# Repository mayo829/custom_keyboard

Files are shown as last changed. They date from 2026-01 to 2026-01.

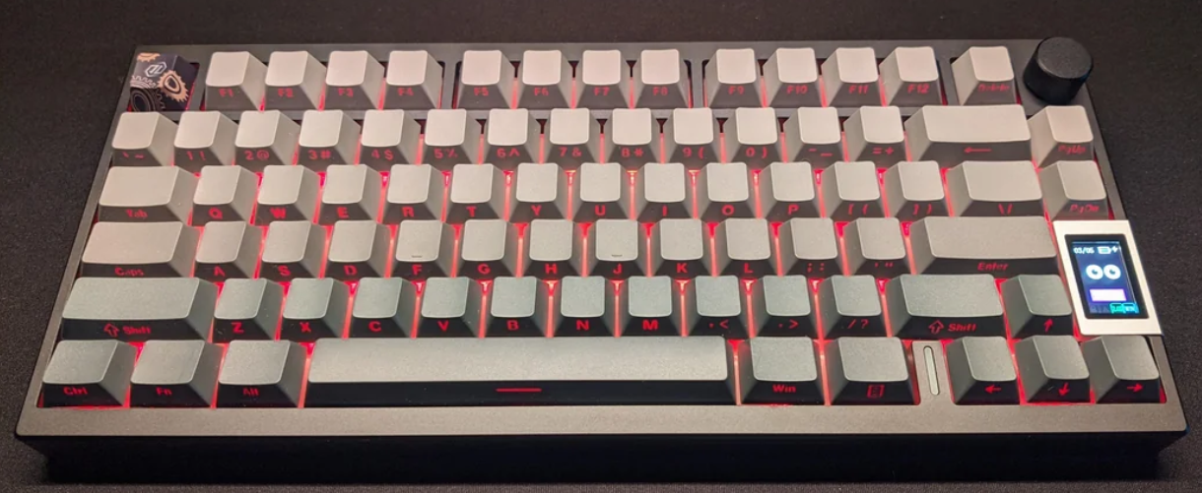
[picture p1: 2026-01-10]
Screenshot 2026-01-09 184816.png

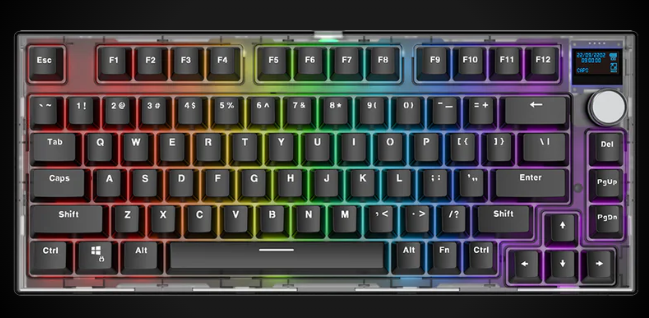
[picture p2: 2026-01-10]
Screenshot 2026-01-09 185157.png

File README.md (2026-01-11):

# Customized keyboard from scratch!

## Requirements
| Device | Requirement Met | Part number |
| LCD display | 0 |
| knob | 0 |
| [rgb backlit](https://www.digikey.com/en/products/detail/sparkfun-electronics/COM-24837/22321085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) | 0 | COM-24837 |
| addressable rgb key lighting | 0 |
| somehow layout the normal 60% plus pgup, pgdn, del, arrows, lcd, and knob and find compatible keycaps (60% keyboard with one extra column) | 0 |
| keycaps need to be, shine-through, square, | 0 |
| case and other stuff to house the keyboard nicely | 0 |
| usbc | 0 |

## BOM
- Mcus:
   - [STM32](https://www.digikey.com/en/products/detail/stmicroelectronics/STM32F072RBT6/4815291s)

- OLED display:
   - [display]()

- Encoder:
   - [encoder](https://www.digikey.com/en/products/detail/bourns-inc/PEC11R-4315K-S0024/7314924)
   - [knob](https://www.digikey.com/en/products/detail/adafruit-industries-llc/5527/16653407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)

- Keycaps
  - [165 key white, grey, red](https://www.aliexpress.us/item/3256803996803052.html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)
  - [correct cool colors](https://www.aliexpress.us/item/3256809279540220.html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)
  
- Switches
  - [Cherry MX2A Silent Red](https://mechanicalkeyboards.com/products/cherry-mx2a-silent-red-45g-linear?variant=48014625145132)

## Resources
- [good guide](https://github.com/ruiqimao/keyboard-pcb-guide)
- [community for keyboard designs](https://kbatelier.org/)
- [reference tutorial](https://www.youtube.com/watch?v=u13yRbBiRYM)

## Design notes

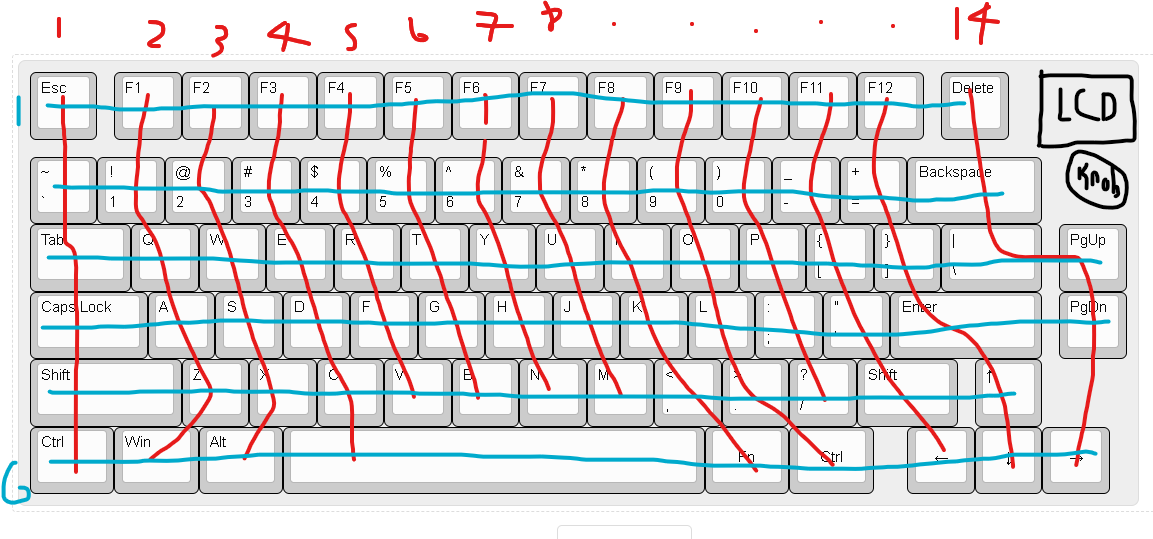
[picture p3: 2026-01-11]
keyboard_layout_image.png

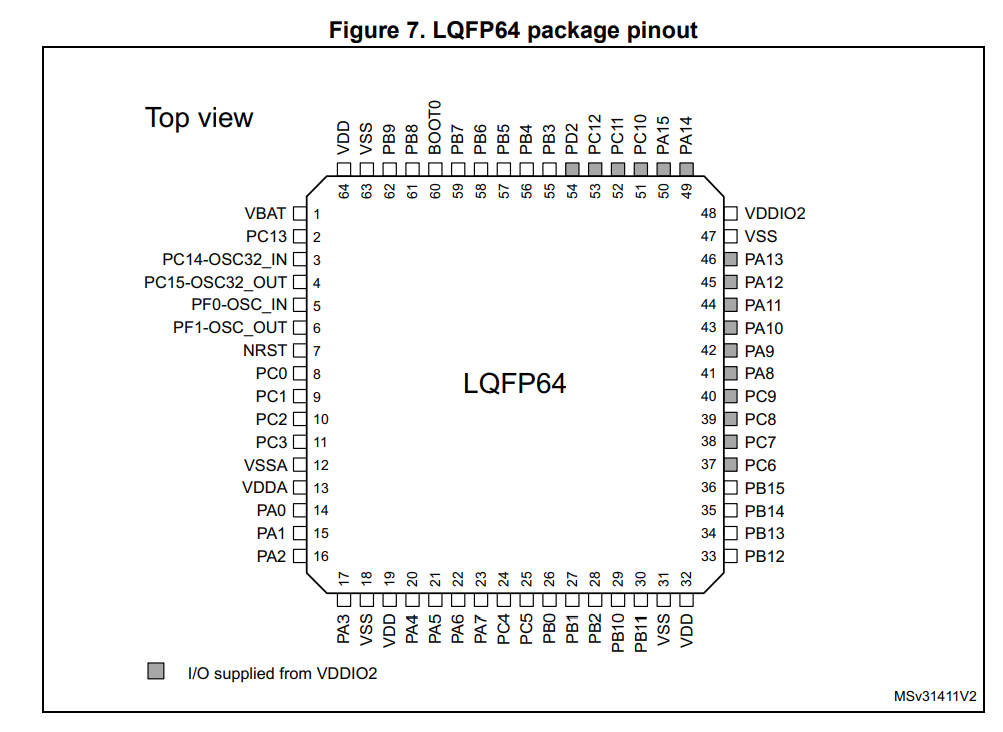
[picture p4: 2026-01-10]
stm32f072rbt6.png

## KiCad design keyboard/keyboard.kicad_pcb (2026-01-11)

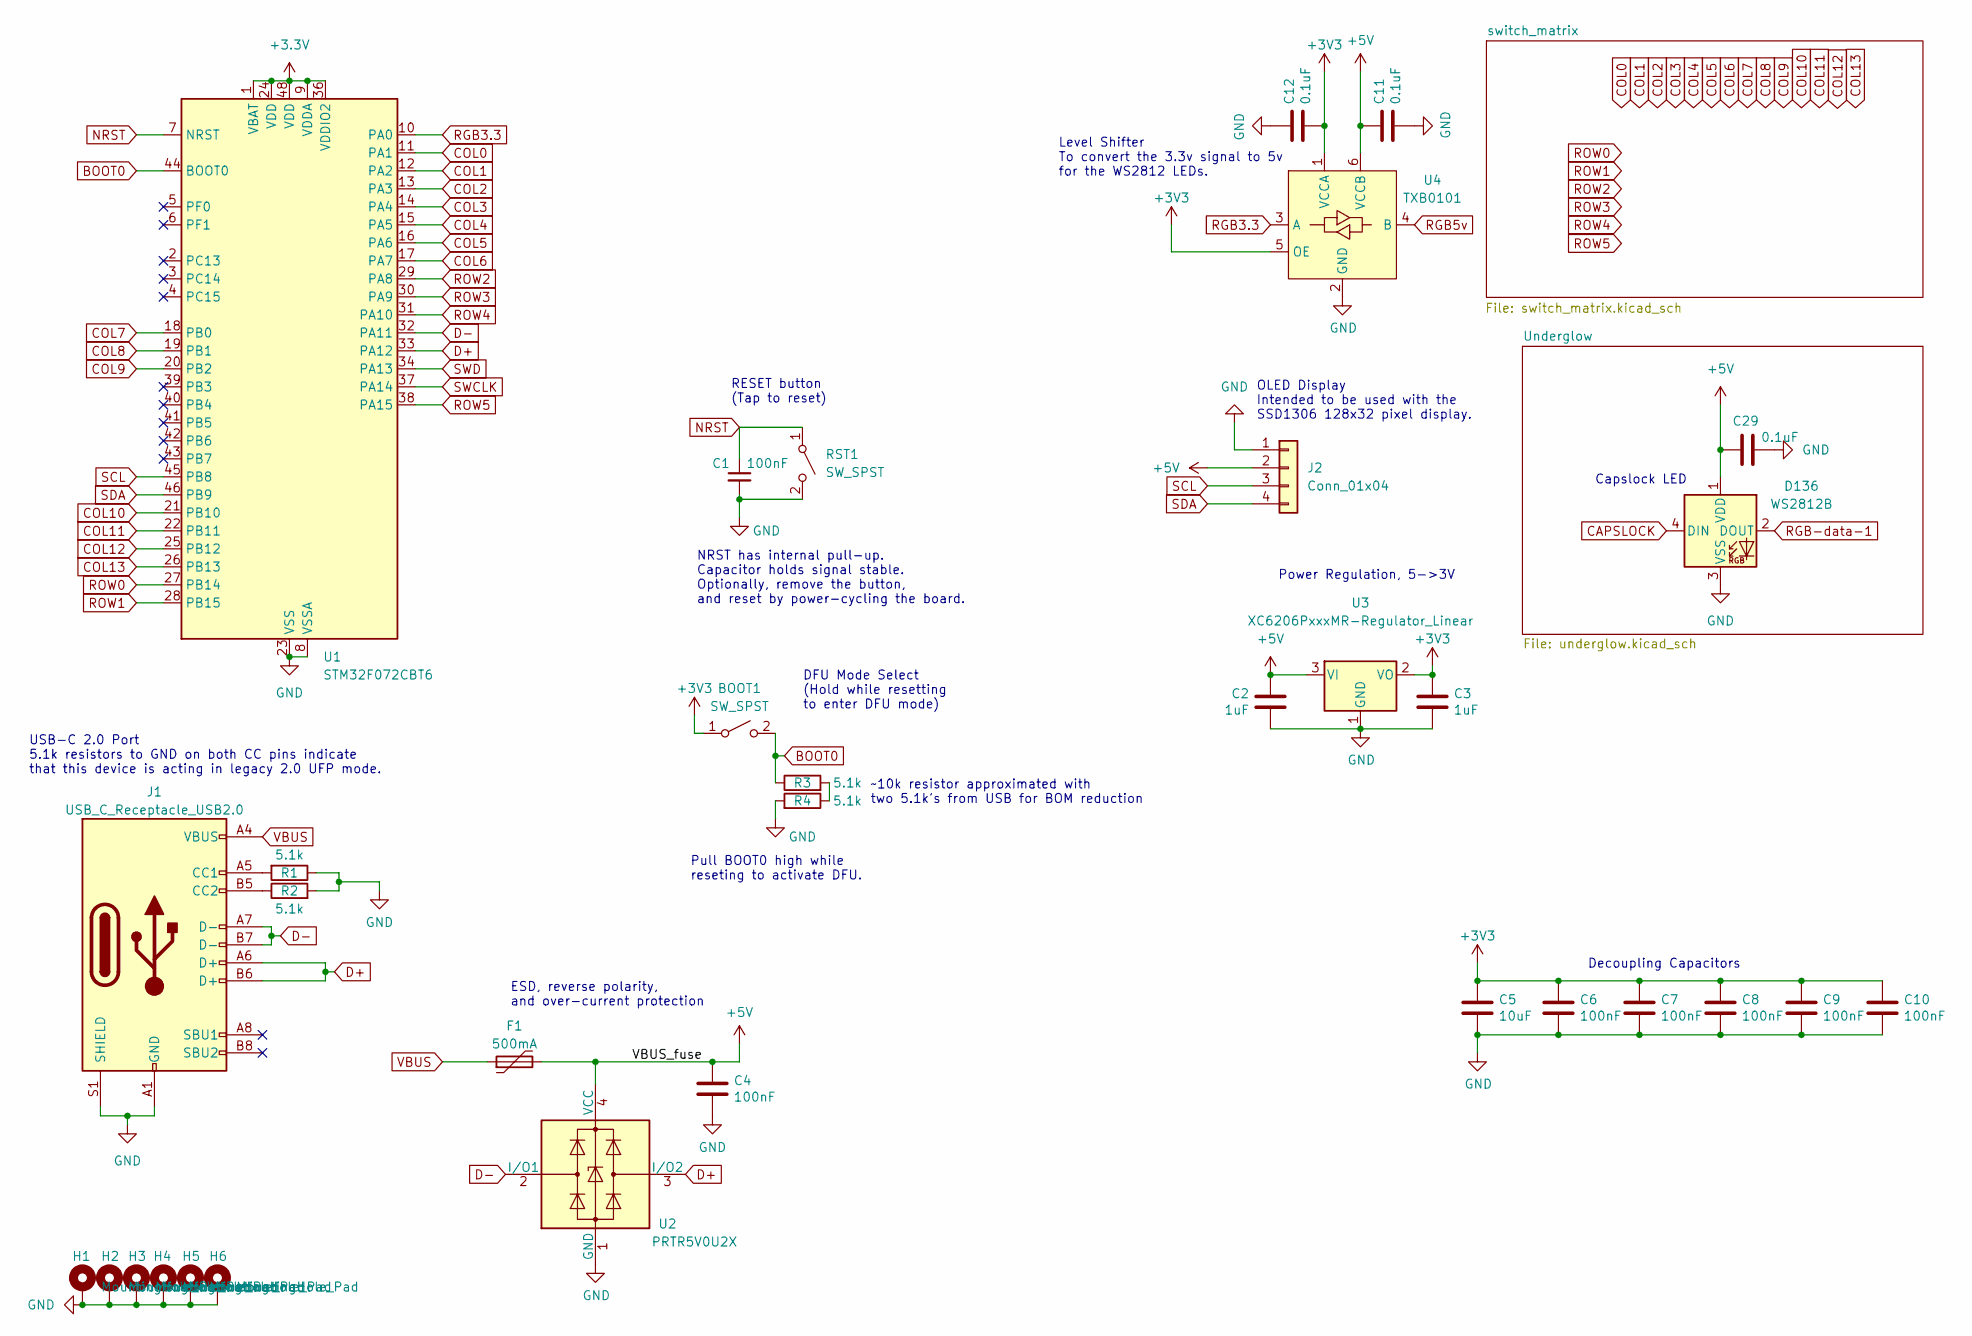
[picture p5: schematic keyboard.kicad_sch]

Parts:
BOOT1: SW_SPST; SW_SPST_TL3342
C1, C4, C6, C7, C8, C9, C10: 100nF; C_0402_1005Metric; LCSC C307331
C2, C3: 1uF; C_0402_1005Metric; LCSC C307331
C5: 10uF; C_0603_1608Metric; LCSC C307331
C11, C12: 0.1uF; C_0402_1005Metric; LCSC C307331
C29: 0.1uF; C_0402_1005Metric
D136: WS2812B; LED_WS2812B_PLCC4_5.0x5.0mm_P3.2mm
F1: 500mA; Fuse_1206_3216Metric; LCSC C135341
H1, H2, H3, H4, H5, H6: MountingHole_Pad; MountingHole_3.2mm_M3
J1: USB_C_Receptacle_USB2.0; USB_C_Receptacle_HRO_TYPE-C-31-M-14; JlcRotOffset 180
J2: Conn_01x04; SSD1306-0.91-OLED-4pin-128x32
R1, R2, R3, R4: 5.1k; R_0402_1005Metric
RST1: SW_SPST; SW_SPST_TL3342
U1: STM32F072CBT6; LQFP-48_7x7mm_P0.5mm
U2: PRTR5V0U2X; SOT-143; LCSC C2827688
U3: XC6206PxxxMR-Regulator_Linear; SOT-23; LCSC C5446
U4: TXB0101; SOT-363_SC-70-6_Handsoldering; LCSC C324081

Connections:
+3.3V: U1.1 (VBAT), U1.9 (VDDA), U1.24 (VDD), U1.36 (VDDIO2), U1.48 (VDD)
+3V3: BOOT1.1 (A), C3.1, C5.1, C6.1, C7.1, C8.1, C9.1, C10.1, C12.2, U3.2 (VO), U4.1 (VCCA), U4.5 (OE)
+5V: C2.1, C4.1, C11.1, C29.1, D136.1 (VDD), F1.2, J2.2, U2.4 (VCC), U3.3 (VI), U4.6 (VCCB); also elsewhere on the board
BOOT0: BOOT1.2 (B), R3.1, U1.44 (BOOT0)
CAPSLOCK: D136.4 (DIN); also elsewhere on the board
COL0: U1.11 (PA1); also elsewhere on the board
COL1: U1.12 (PA2); also elsewhere on the board
COL2: U1.13 (PA3); also elsewhere on the board
COL3: U1.14 (PA4); also elsewhere on the board
COL4: U1.15 (PA5); also elsewhere on the board
COL5: U1.16 (PA6); also elsewhere on the board
COL6: U1.17 (PA7); also elsewhere on the board
COL7: U1.18 (PB0); also elsewhere on the board
COL8: U1.19 (PB1); also elsewhere on the board
COL9: U1.20 (PB2); also elsewhere on the board
COL10: U1.21 (PB10); also elsewhere on the board
COL11: U1.22 (PB11); also elsewhere on the board
COL12: U1.25 (PB12); also elsewhere on the board
COL13: U1.26 (PB13); also elsewhere on the board
D+: J1.A6 (D+), J1.B6 (D+), U1.33 (PA12), U2.3 (I/O2)
D-: J1.A7 (D-), J1.B7 (D-), U1.32 (PA11), U2.2 (I/O1)
GND: C1.2, C2.2, C3.2, C4.2, C5.2, C6.2, C7.2, C8.2, C9.2, C10.2, C11.2, C12.1, C29.2, D136.3 (VSS), H1.1, H2.1, H3.1, H4.1, H5.1, H6.1, J1.A1 (GND), J1.A12 (GND), J1.B1 (GND), J1.B12 (GND), J1.S1 (SHIELD), J2.1, R1.1, R2.2, R4.2, RST1.2 (B), U1.8 (VSSA), U1.23 (VSS), U1.35 (VSS), U1.47 (VSS), U2.1 (GND), U3.1 (GND), U4.2 (GND); also elsewhere on the board
NRST: C1.1, RST1.1 (A), U1.7 (NRST)
unnamed: J1.A5 (CC1), R1.2
unnamed: J1.B5 (CC2), R2.1
unnamed: R3.2, R4.1
RGB3.3: U1.10 (PA0), U4.3 (A)
RGB5v: U4.4 (B); also elsewhere on the board
RGB-data-1: D136.2 (DOUT); also elsewhere on the board
ROW0: U1.27 (PB14); also elsewhere on the board
ROW1: U1.28 (PB15); also elsewhere on the board
ROW2: U1.29 (PA8); also elsewhere on the board
ROW3: U1.30 (PA9); also elsewhere on the board
ROW4: U1.31 (PA10); also elsewhere on the board
ROW5: U1.38 (PA15); also elsewhere on the board
SCL: J2.3, U1.45 (PB8)
SDA: J2.4, U1.46 (PB9)
SWCLK: U1.37 (PA14)
SWD: U1.34 (PA13)
VBUS: F1.1, J1.A4 (VBUS), J1.A9 (VBUS), J1.B4 (VBUS), J1.B9 (VBUS)

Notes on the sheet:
Decoupling Capacitors
~10k resistor approximated with two 5.1k's from USB for BOM reduction
RESET button (Tap to reset)
Power Regulation, 5->3V
Pull BOOT0 high while reseting to activate DFU.
Capslock LED
USB-C 2.0 Port 5.1k resistors to GND on both CC pins indicate that this device is acting in legacy 2.0 UFP mode.
NRST has internal pull-up. Capacitor holds signal stable. Optionally, remove the button, and reset by power-cycling the board.
ESD, reverse polarity, and over-current protection
Level Shifter To convert the 3.3v signal to 5v for the WS2812 LEDs.
OLED Display Intended to be used with the SSD1306 128x32 pixel display.
DFU Mode Select (Hold while resetting to enter DFU mode)

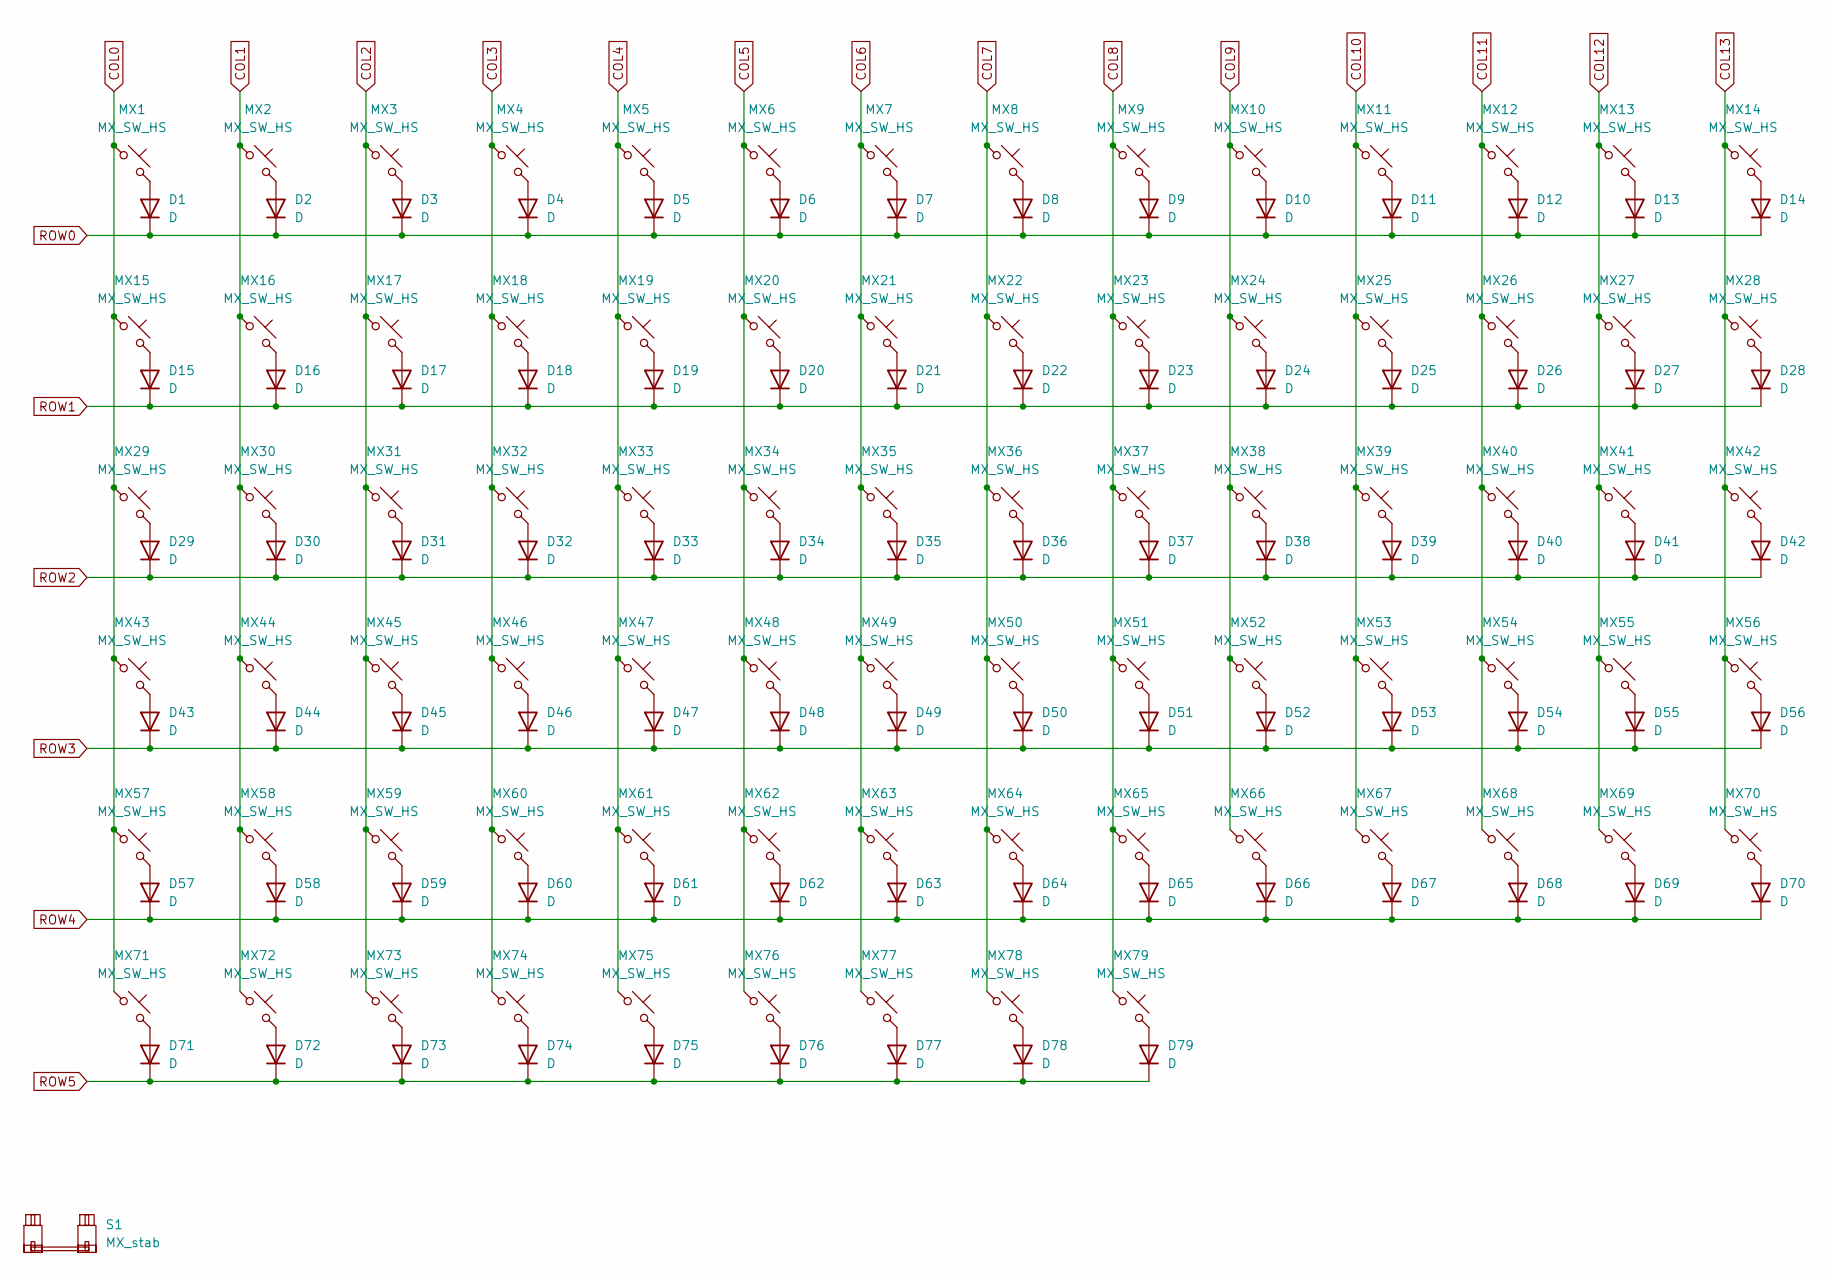
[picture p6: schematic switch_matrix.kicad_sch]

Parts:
D1, D2, D3, D4, D5, D6, D7, D8, D9, D10, D11, D12, D13, D14, D15, D16, D17, D18, D19, D20, D21, D22, D23, D24, D25, D26, D27, D28, D29, D30, D31, D32, D33, D34, D35, D36, D37, D38, D39, D40, D41, D42, D43, D44, D45, D46, D47, D48, D49, D50, D51, D52, D53, D54, D55, D56, D57, D58, D59, D60, D61, D62, D63, D64, D65, D66, D67, D68, D69, D70, D71, D72, D73, D74, D75, D76, D77, D78, D79: D; D_SOD-123
MX1, MX2, MX3, MX4, MX5, MX6, MX7, MX8, MX9, MX10, MX11, MX12, MX13, MX14, MX15, MX16, MX17, MX18, MX19, MX20, MX21, MX22, MX23, MX24, MX25, MX26, MX27, MX28, MX29, MX30, MX31, MX32, MX33, MX34, MX35, MX36, MX37, MX38, MX39, MX40, MX41, MX42, MX43, MX44, MX45, MX46, MX47, MX48, MX49, MX50, MX51, MX52, MX53, MX54, MX55, MX56, MX57, MX58, MX59, MX60, MX61, MX62, MX63, MX64, MX65, MX66, MX67, MX68, MX69, MX70, MX71, MX72, MX73, MX74, MX75, MX76, MX77, MX78, MX79: MX_SW_HS; SW_MX_HS_CPG151101S11_1u
S1: MX_stab; STAB_MX_P_6.25u

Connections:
COL0: MX1.1, MX15.1, MX29.1, MX43.1, MX57.1, MX71.1; also elsewhere on the board
COL1: MX2.1, MX16.1, MX30.1, MX44.1, MX58.1, MX72.1; also elsewhere on the board
COL2: MX3.1, MX17.1, MX31.1, MX45.1, MX59.1, MX73.1; also elsewhere on the board
COL3: MX4.1, MX18.1, MX32.1, MX46.1, MX60.1, MX74.1; also elsewhere on the board
COL4: MX5.1, MX19.1, MX33.1, MX47.1, MX61.1, MX75.1; also elsewhere on the board
COL5: MX6.1, MX20.1, MX34.1, MX48.1, MX62.1, MX76.1; also elsewhere on the board
COL6: MX7.1, MX21.1, MX35.1, MX49.1, MX63.1, MX77.1; also elsewhere on the board
COL7: MX8.1, MX22.1, MX36.1, MX50.1, MX64.1, MX78.1; also elsewhere on the board
COL8: MX9.1, MX23.1, MX37.1, MX51.1, MX65.1, MX79.1; also elsewhere on the board
COL9: MX10.1, MX24.1, MX38.1, MX52.1, MX66.1; also elsewhere on the board
COL10: MX11.1, MX25.1, MX39.1, MX53.1, MX67.1; also elsewhere on the board
COL11: MX12.1, MX26.1, MX40.1, MX54.1, MX68.1; also elsewhere on the board
COL12: MX13.1, MX27.1, MX41.1, MX55.1, MX69.1; also elsewhere on the board
COL13: MX14.1, MX28.1, MX42.1, MX56.1, MX70.1; also elsewhere on the board
unnamed: D1.2 (A), MX1.2
unnamed: D2.2 (A), MX2.2
unnamed: D3.2 (A), MX3.2
unnamed: D4.2 (A), MX4.2
unnamed: D5.2 (A), MX5.2
unnamed: D6.2 (A), MX6.2
unnamed: D7.2 (A), MX7.2
unnamed: D8.2 (A), MX8.2
unnamed: D9.2 (A), MX9.2
unnamed: D10.2 (A), MX10.2
unnamed: D11.2 (A), MX11.2
unnamed: D12.2 (A), MX12.2
unnamed: D13.2 (A), MX13.2
unnamed: D14.2 (A), MX14.2
unnamed: D15.2 (A), MX15.2
unnamed: D16.2 (A), MX16.2
unnamed: D17.2 (A), MX17.2
unnamed: D18.2 (A), MX18.2
unnamed: D19.2 (A), MX19.2
unnamed: D20.2 (A), MX20.2
unnamed: D21.2 (A), MX21.2
unnamed: D22.2 (A), MX22.2
unnamed: D23.2 (A), MX23.2
unnamed: D24.2 (A), MX24.2
unnamed: D25.2 (A), MX25.2
unnamed: D26.2 (A), MX26.2
unnamed: D27.2 (A), MX27.2
unnamed: D28.2 (A), MX28.2
unnamed: D29.2 (A), MX29.2
unnamed: D30.2 (A), MX30.2
unnamed: D31.2 (A), MX31.2
unnamed: D32.2 (A), MX32.2
unnamed: D33.2 (A), MX33.2
unnamed: D34.2 (A), MX34.2
unnamed: D35.2 (A), MX35.2
unnamed: D36.2 (A), MX36.2
unnamed: D37.2 (A), MX37.2
unnamed: D38.2 (A), MX38.2
unnamed: D39.2 (A), MX39.2
unnamed: D40.2 (A), MX40.2
unnamed: D41.2 (A), MX41.2
unnamed: D42.2 (A), MX42.2
unnamed: D43.2 (A), MX43.2
unnamed: D44.2 (A), MX44.2
unnamed: D45.2 (A), MX45.2
unnamed: D46.2 (A), MX46.2
unnamed: D47.2 (A), MX47.2
unnamed: D48.2 (A), MX48.2
unnamed: D49.2 (A), MX49.2
unnamed: D50.2 (A), MX50.2
unnamed: D51.2 (A), MX51.2
unnamed: D52.2 (A), MX52.2
unnamed: D53.2 (A), MX53.2
unnamed: D54.2 (A), MX54.2
unnamed: D55.2 (A), MX55.2
unnamed: D56.2 (A), MX56.2
unnamed: D57.2 (A), MX57.2
unnamed: D58.2 (A), MX58.2
unnamed: D59.2 (A), MX59.2
unnamed: D60.2 (A), MX60.2
unnamed: D61.2 (A), MX61.2
unnamed: D62.2 (A), MX62.2
unnamed: D63.2 (A), MX63.2
unnamed: D64.2 (A), MX64.2
unnamed: D65.2 (A), MX65.2
unnamed: D66.2 (A), MX66.2
unnamed: D67.2 (A), MX67.2
unnamed: D68.2 (A), MX68.2
unnamed: D69.2 (A), MX69.2
unnamed: D70.2 (A), MX70.2
unnamed: D71.2 (A), MX71.2
unnamed: D72.2 (A), MX72.2
unnamed: D73.2 (A), MX73.2
unnamed: D74.2 (A), MX74.2
unnamed: D75.2 (A), MX75.2
unnamed: D76.2 (A), MX76.2
unnamed: D77.2 (A), MX77.2
unnamed: D78.2 (A), MX78.2
unnamed: D79.2 (A), MX79.2
ROW0: D1.1 (K), D2.1 (K), D3.1 (K), D4.1 (K), D5.1 (K), D6.1 (K), D7.1 (K), D8.1 (K), D9.1 (K), D10.1 (K), D11.1 (K), D12.1 (K), D13.1 (K), D14.1 (K); also elsewhere on the board
ROW1: D15.1 (K), D16.1 (K), D17.1 (K), D18.1 (K), D19.1 (K), D20.1 (K), D21.1 (K), D22.1 (K), D23.1 (K), D24.1 (K), D25.1 (K), D26.1 (K), D27.1 (K), D28.1 (K); also elsewhere on the board
ROW2: D29.1 (K), D30.1 (K), D31.1 (K), D32.1 (K), D33.1 (K), D34.1 (K), D35.1 (K), D36.1 (K), D37.1 (K), D38.1 (K), D39.1 (K), D40.1 (K), D41.1 (K), D42.1 (K); also elsewhere on the board
ROW3: D43.1 (K), D44.1 (K), D45.1 (K), D46.1 (K), D47.1 (K), D48.1 (K), D49.1 (K), D50.1 (K), D51.1 (K), D52.1 (K), D53.1 (K), D54.1 (K), D55.1 (K), D56.1 (K); also elsewhere on the board
ROW4: D57.1 (K), D58.1 (K), D59.1 (K), D60.1 (K), D61.1 (K), D62.1 (K), D63.1 (K), D64.1 (K), D65.1 (K), D66.1 (K), D67.1 (K), D68.1 (K), D69.1 (K), D70.1 (K); also elsewhere on the board
ROW5: D71.1 (K), D72.1 (K), D73.1 (K), D74.1 (K), D75.1 (K), D76.1 (K), D77.1 (K), D78.1 (K), D79.1 (K); also elsewhere on the board

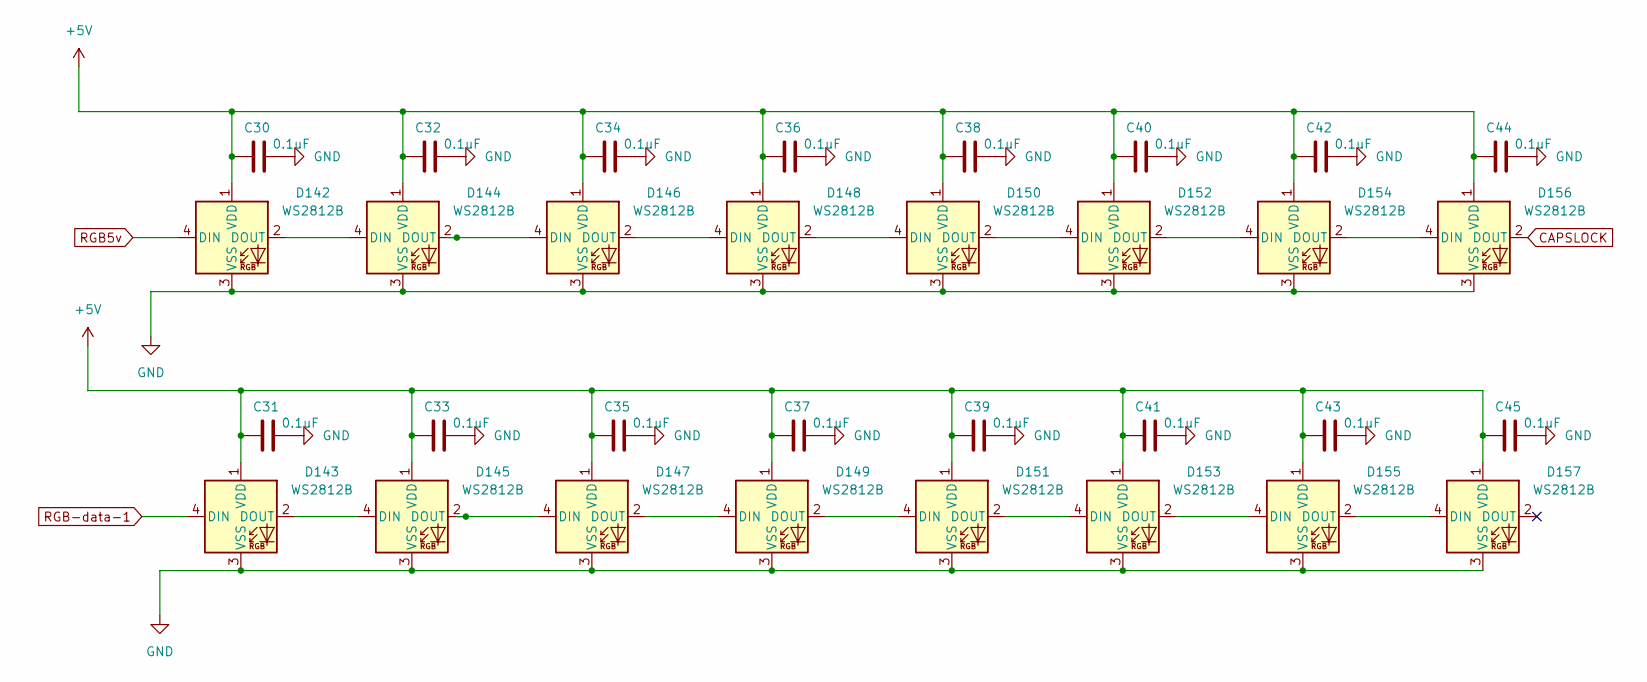
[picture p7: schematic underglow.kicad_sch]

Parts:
C30, C31, C32, C33, C34, C35, C36, C37, C38, C39, C40, C41, C42, C43, C44, C45: 0.1uF; C_0402_1005Metric
D142, D143, D144, D145, D146, D147, D148, D149, D150, D151, D152, D153, D154, D155, D156, D157: WS2812B; LED_WS2812B_PLCC4_5.0x5.0mm_P3.2mm

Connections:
+5V: C30.1, C31.1, C32.1, C33.1, C34.1, C35.1, C36.1, C37.1, C38.1, C39.1, C40.1, C41.1, C42.1, C43.1, C44.1, C45.1, D142.1 (VDD), D143.1 (VDD), D144.1 (VDD), D145.1 (VDD), D146.1 (VDD), D147.1 (VDD), D148.1 (VDD), D149.1 (VDD), D150.1 (VDD), D151.1 (VDD), D152.1 (VDD), D153.1 (VDD), D154.1 (VDD), D155.1 (VDD), D156.1 (VDD), D157.1 (VDD); also elsewhere on the board
CAPSLOCK: D156.2 (DOUT); also elsewhere on the board
GND: C30.2, C31.2, C32.2, C33.2, C34.2, C35.2, C36.2, C37.2, C38.2, C39.2, C40.2, C41.2, C42.2, C43.2, C44.2, C45.2, D142.3 (VSS), D143.3 (VSS), D144.3 (VSS), D145.3 (VSS), D146.3 (VSS), D147.3 (VSS), D148.3 (VSS), D149.3 (VSS), D150.3 (VSS), D151.3 (VSS), D152.3 (VSS), D153.3 (VSS), D154.3 (VSS), D155.3 (VSS), D156.3 (VSS), D157.3 (VSS); also elsewhere on the board
unnamed: D142.2 (DOUT), D144.4 (DIN)
unnamed: D143.2 (DOUT), D145.4 (DIN)
unnamed: D144.2 (DOUT), D146.4 (DIN)
unnamed: D145.2 (DOUT), D147.4 (DIN)
unnamed: D146.2 (DOUT), D148.4 (DIN)
unnamed: D147.2 (DOUT), D149.4 (DIN)
unnamed: D148.2 (DOUT), D150.4 (DIN)
unnamed: D149.2 (DOUT), D151.4 (DIN)
unnamed: D150.2 (DOUT), D152.4 (DIN)
unnamed: D151.2 (DOUT), D153.4 (DIN)
unnamed: D152.2 (DOUT), D154.4 (DIN)
unnamed: D153.2 (DOUT), D155.4 (DIN)
unnamed: D154.2 (DOUT), D156.4 (DIN)
unnamed: D155.2 (DOUT), D157.4 (DIN)
RGB5v: D142.4 (DIN); also elsewhere on the board
RGB-data-1: D143.4 (DIN); also elsewhere on the board

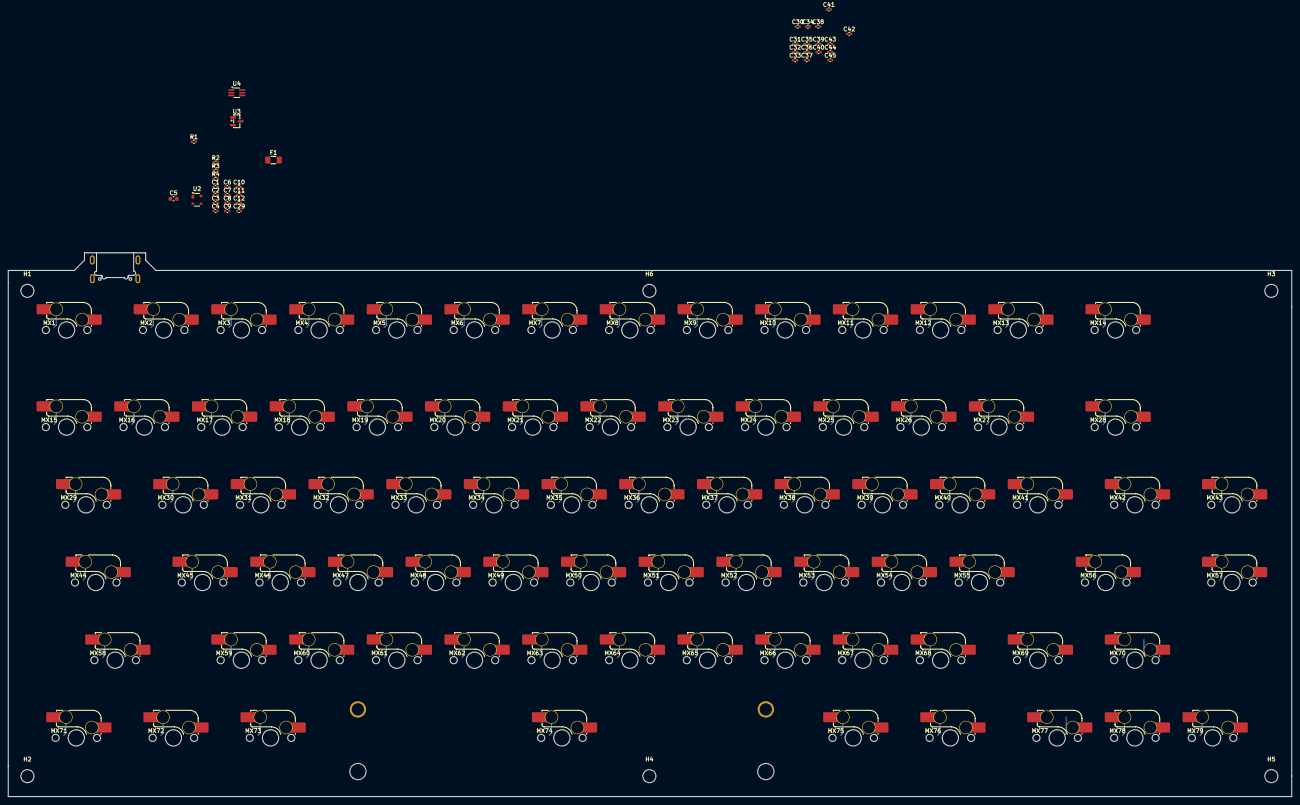
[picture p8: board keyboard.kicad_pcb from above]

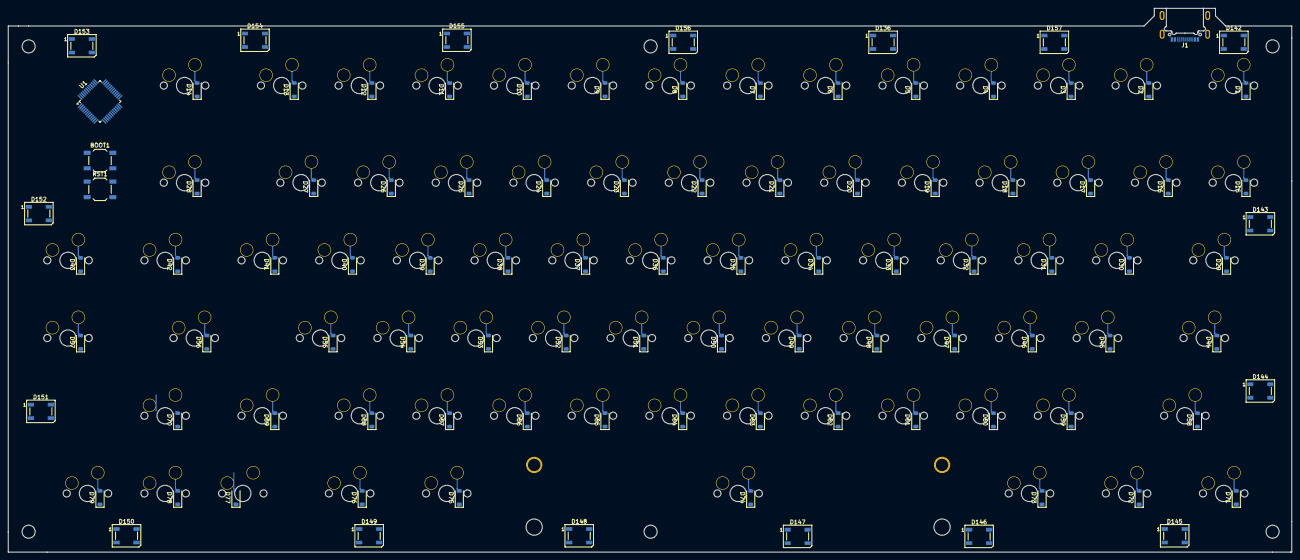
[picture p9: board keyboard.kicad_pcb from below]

Board: 2 copper layers, 314.7 x 133.3 mm, 223 parts (100 on the bottom side), 129 nets.

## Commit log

2026-01-09 resources and BOM
2026-01-09 Fix formatting in README for BOM and Resources sections
2026-01-11 auto push
    [keyboard.kicad_pcb, keyboard.kicad_sch, switch_matrix.kicad_sch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]
